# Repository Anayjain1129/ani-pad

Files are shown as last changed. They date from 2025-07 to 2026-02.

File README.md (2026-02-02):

# Ani-Pad
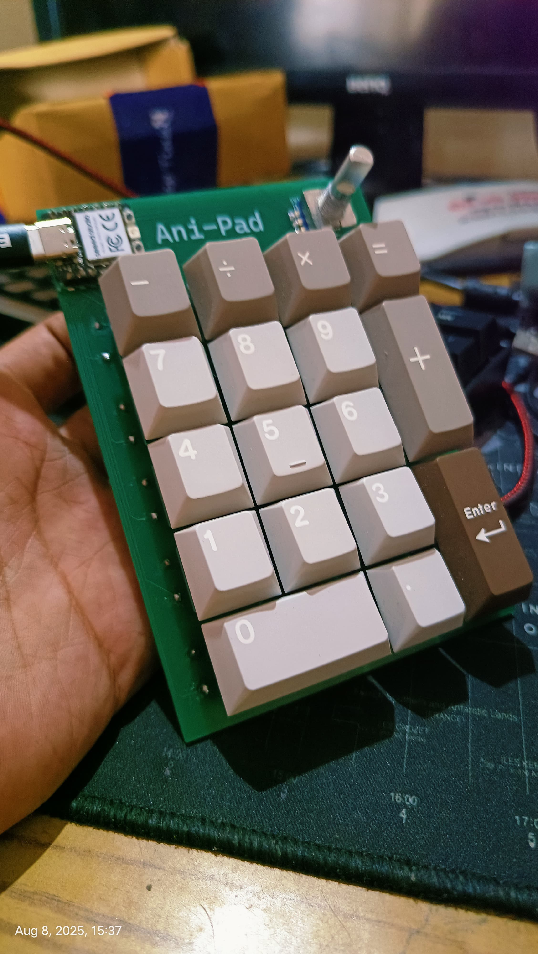
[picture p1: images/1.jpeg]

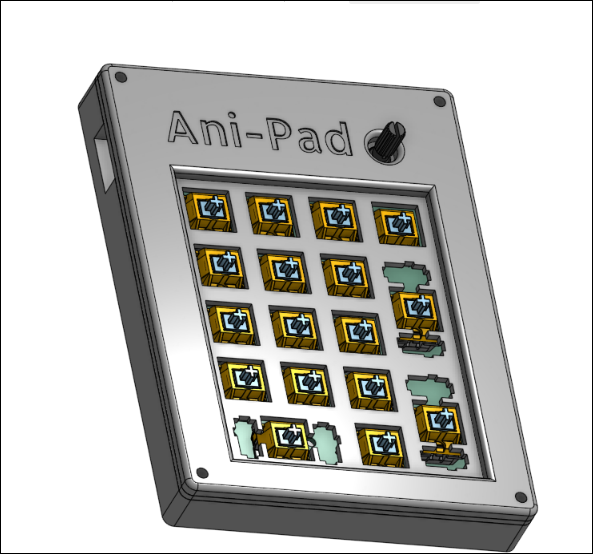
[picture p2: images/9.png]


### Why did I make it?
As I already made hackpad So i wanna make sure that this submission is not hackpad
This is a easier project for highway. So, i made this project cause I use a 60% keeb which does not have a numpad and I really needed that so i asked alex can i make one and got a yes so here we go

### What was the hardest part about this ?
I had tons of issues with making the Firmware, I was really fucked up on Firmware part but I made through.

Features:

- EC11 Rotary Encoder - For Volume, Brightness etc
- 17x keys
- XIAO rp2040
- Traditional Numpad Layout
- QMK firmware
  
### Schematic
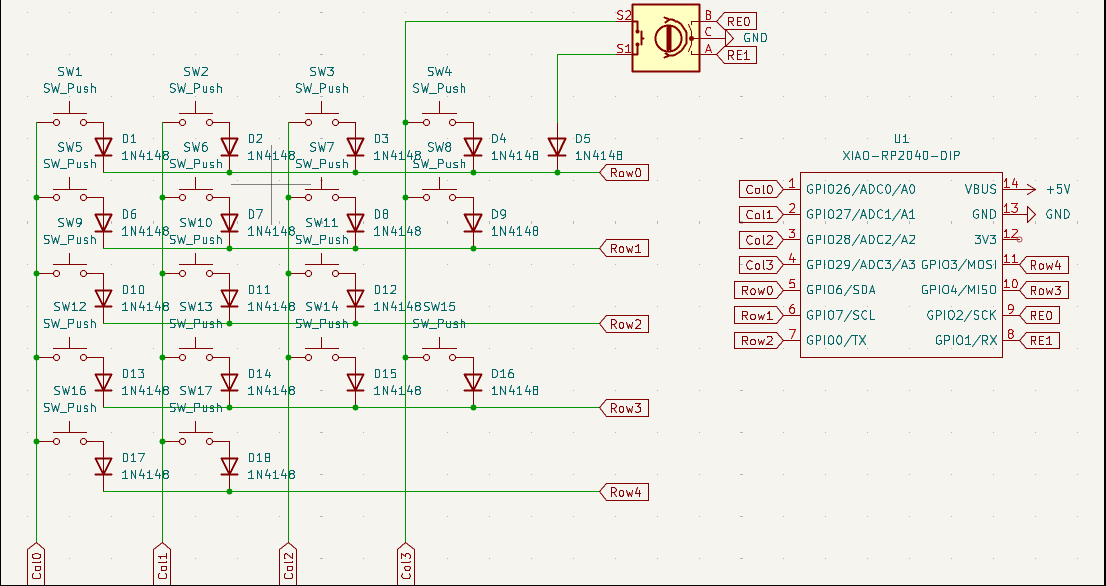
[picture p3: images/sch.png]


### PCB 
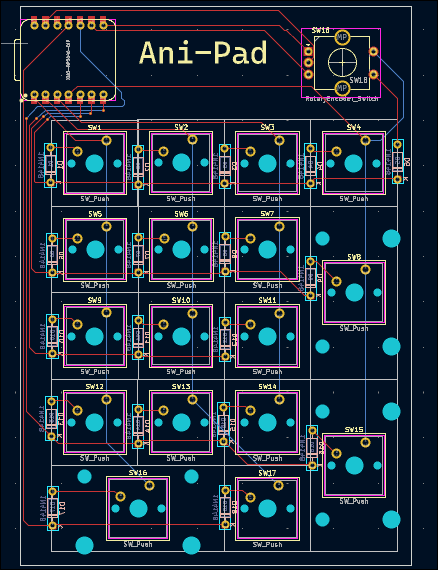
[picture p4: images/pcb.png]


### Case
- Bottom
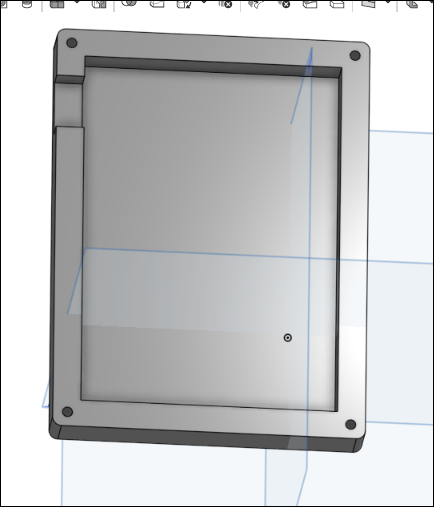
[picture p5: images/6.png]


-Middle plate
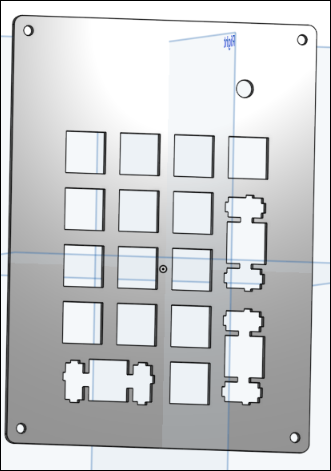
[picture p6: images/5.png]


- Top
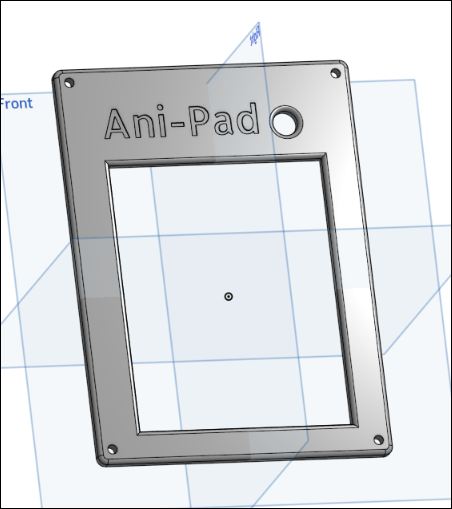
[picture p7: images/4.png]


### 3D view of all parts together 
-PCB
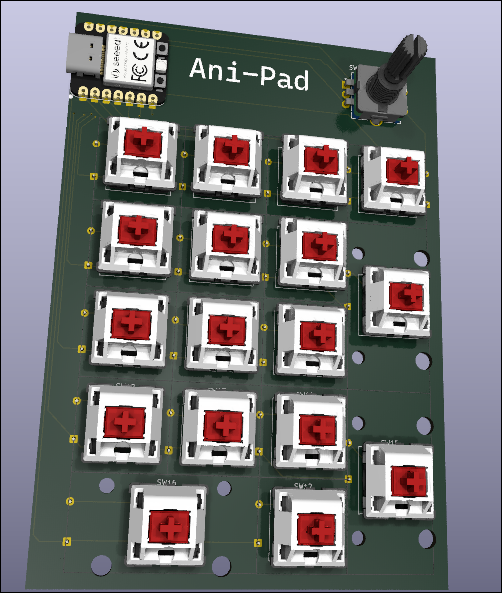
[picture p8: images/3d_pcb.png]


-CAD
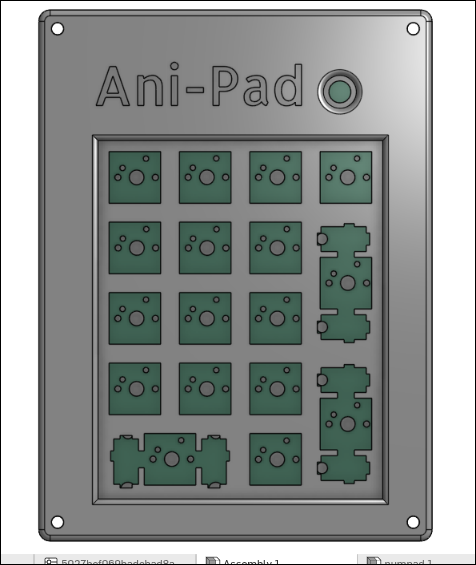
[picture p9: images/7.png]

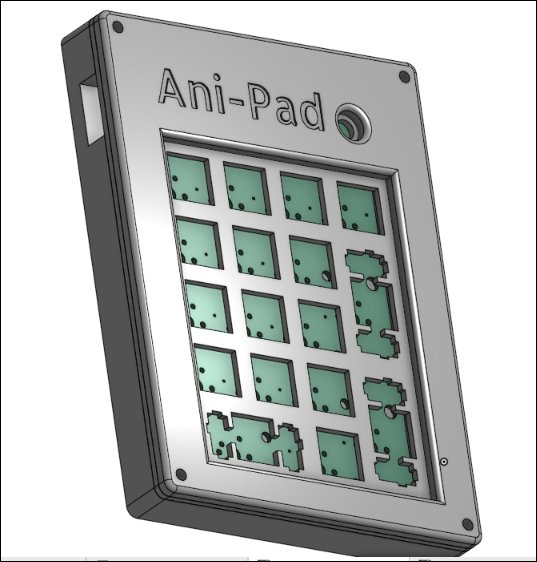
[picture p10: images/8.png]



#Yoututb Link
https://youtube.com/shorts/V-X0GS2zixY?si=X8VkAyLvjKdzDLy9

### BOM
| Name | Qty | Final Price - INR (USD) | Link |
| --- | --- | --- | --- |
| Gateron EF Grayish | 20  | 390 ($4.55) | [here](https://neomacro.in/products/gateron-ef-grayish) |
| Genuine Cherry MX Plate Mount Stabilizers 2U | 3 | 400 {$4.67} | [here](https://stackskb.com/store/genuine-cherry-mx-plate-mount-stabilizers-2u/) |
| KeyKobo Jindo Keycap Set | 1 | 1,700 ($19.84) | [here](https://neomacro.in/products/key-kobo-jindo-keycap-set?_pos=3&_sid=b1e2b9343&_ss=r&variant=48328446116118) |
| Diode 1N4148 Through - Hole | 100 | 169 ($1.97) | [here](https://amzn.in/d/j3eLvoh) |
| EC11 Rotary Encoder | 2 | 178 ($2.08) | [here](https://amzn.in/d/hVRxzij) |
| M3 x 20mm Bolt | 15  | 149 ($1.73) | [here](https://amzn.in/d/8GRQWAB) |
| M3 Nuts | 8 | 100 ($1.16) | [here](https://amzn.in/d/7UQtsm8) |
| M3 x 5mm Heatset Insert | 25  | 179 ($2.09) | [here](https://amzn.in/d/ixybuAc) |
| PCB | 5 | 2,282 ($26.63) | 
| XIAO 2040 | 1 | 1,340 ($15.64) | [here](https://www.amazon.in/Microcontroller-Dual-Core-MicroPython-CircuitPython-Interfaces/dp/B09NNVNW7M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)|
| Top Case | 1 | Print Legion |
| Bottom Case | 1 | Print Legion |
| Middle Plate | 1 | Print Legion |

## Total Pricing 

This Numpad comes out to be 6887 INR ($80.36) When ordering all the parts I'm not including  the 3D parts because I will be getting them from Print Legion.

## Notes :-

I want all the three 3D-printed parts to be printed in black color.
The pricing might slightly vary due to flash sales, and dollar market trends.

## Changes for reboot 
https://drive.google.com/file/d/1S1DNsVMGy2zWwLPmCcZhrC4ZR8giEo4_/view?usp=sharing

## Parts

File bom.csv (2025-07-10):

Name | Qty | Final Price- INR (USD) | Link
Gateron EF Grayish | 20 | 390 ($4.55) | https://neomacro.in/products/gateron-ef-grayish
Genuine Cherry MX Plate Mount Stabilizers 2U | 3 | 400 ($4.67) | https://stackskb.com/store/genuine-cherry-mx-plate-mount-stabilizers-2u/
KeyKobo Jindo Keycap Set | 1 | 1,700 ($19.84) | https://neomacro.in/products/key-kobo-jindo-keycap-set?_pos=3&_sid=b1e2b9343&_ss=r&variant=48328446116118
Diode 1N4148 Through – Hole | 100 | 169 ($1.97) | https://amzn.in/d/j3eLvoh
EC11 Rotary Encoder | 2 | 178 ($2.08) | https://amzn.in/d/hVRxzij
M3 x 20mm Bolt | 15 | 149 ($1.73) | https://amzn.in/d/8GRQWAB
M3 Nuts | 8 | 100 ($1.16) | https://amzn.in/d/7UQtsm8
M3 x 5mm Heatset Insert | 25 | 179 ($2.09) | https://amzn.in/d/ixybuAc
PCB | 5 | 2,282 ($26.63)
XIAO RP2040 | 1 | 1,340 ($15.64) | https://www.amazon.in/Microcontroller-Dual-Core-MicroPython-CircuitPython-Interfaces/dp/B09NNVNW7M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
Top Case | 1 | Print Legion
Bottom Case | 1 | Print Legion
Middle Plate | 1 | Print Legion

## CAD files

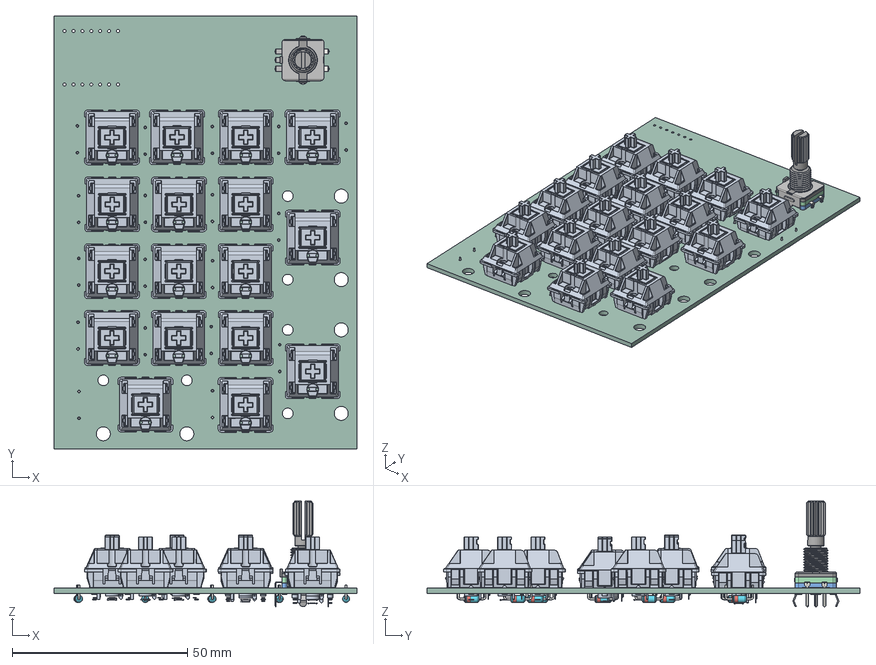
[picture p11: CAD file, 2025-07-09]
PCB/numpad.step
86.3 x 123.4 x 30.1 mm
numpad 1.1.1 x 17
EC11_Rotary_Encoder_Switched
D_DO-35_SOD27_P7.62mm_Horizontal x 18
numpad_PCB

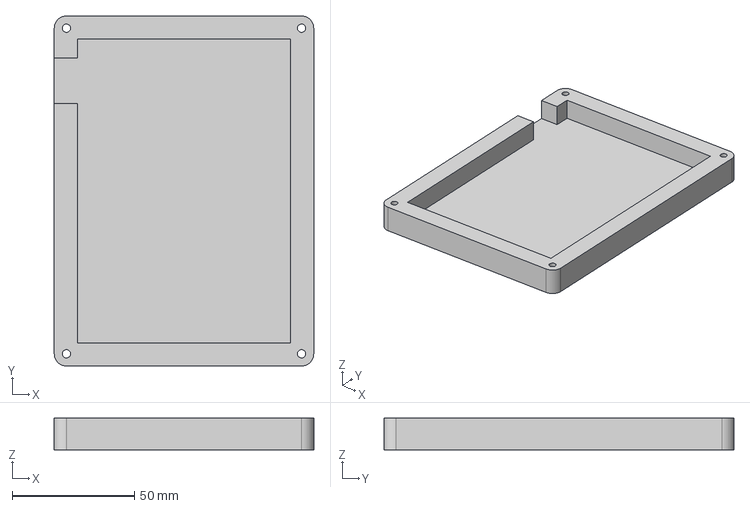
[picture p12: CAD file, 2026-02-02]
Production/CAD/bot.step
106.3 x 143.4 x 13.0 mm

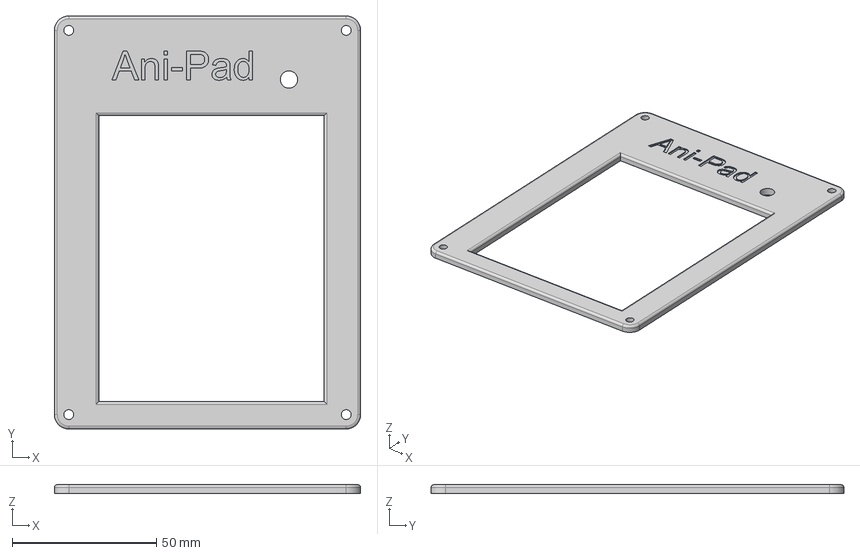
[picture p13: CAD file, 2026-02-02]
Production/CAD/top.step
106.3 x 143.4 x 3.00 mm

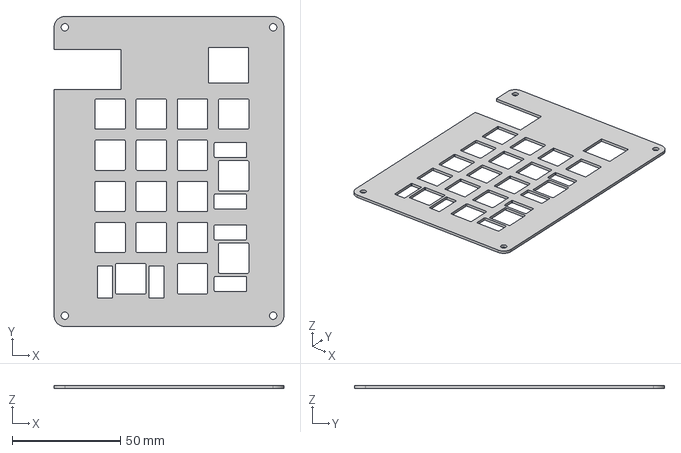
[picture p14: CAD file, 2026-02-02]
Production/CAD/mid.step
106.3 x 143.4 x 1.50 mm

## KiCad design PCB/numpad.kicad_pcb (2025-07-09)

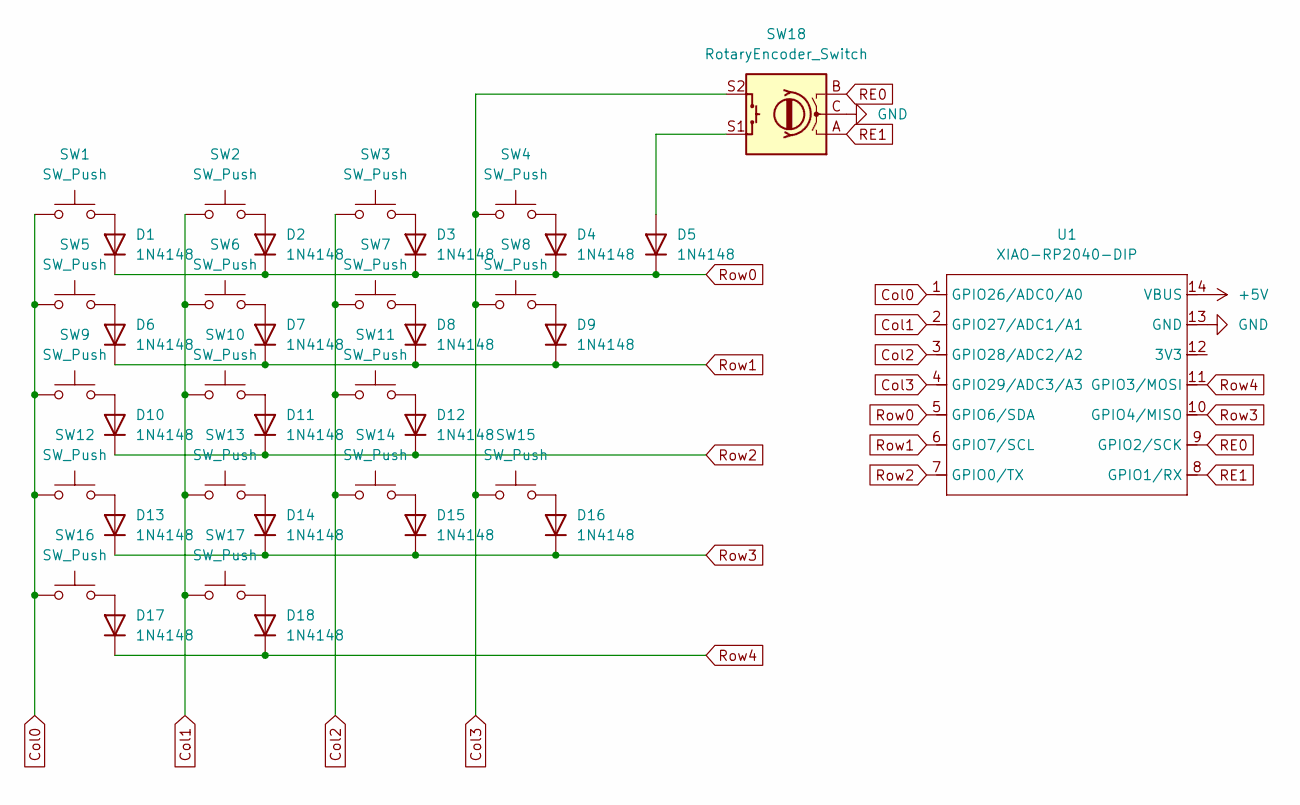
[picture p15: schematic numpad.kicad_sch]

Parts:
D1, D2, D3, D4, D5, D6, D7, D8, D9, D10, D11, D12, D13, D14, D15, D16, D17, D18: 1N4148; D_DO-35_SOD27_P7.62mm_Horizontal
SW1, SW2, SW3, SW4, SW5, SW6, SW7, SW9, SW10, SW11, SW12, SW13, SW14, SW17: SW_Push; SW_Cherry_MX_1.00u_PCB
SW8, SW15: SW_Push; SW_Cherry_MX_2.00u_Vertical_PCB
SW16: SW_Push; SW_Cherry_MX_2.00u_PCB
SW18: RotaryEncoder_Switch; RotaryEncoder_Alps_EC11E-Switch_Vertical_H20mm_CircularMoun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
U1: XIAO-RP2040-DIP

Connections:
+5V: U1.14 (VBUS)
Col0: SW1.1, SW5.1, SW9.1, SW12.1, SW16.1, U1.1 (GPIO26/ADC0/A0)
Col1: SW2.1, SW6.1, SW10.1, SW13.1, SW17.1, U1.2 (GPIO27/ADC1/A1)
Col2: SW3.1, SW7.1, SW11.1, SW14.1, U1.3 (GPIO28/ADC2/A2)
Col3: SW4.1, SW8.1, SW15.1, SW18.S2, U1.4 (GPIO29/ADC3/A3)
GND: SW18.C, U1.13 (GND)
unnamed: D1.2 (A), SW1.2
unnamed: D2.2 (A), SW2.2
unnamed: D3.2 (A), SW3.2
unnamed: D4.2 (A), SW4.2
unnamed: D5.2 (A), SW18.S1
unnamed: D6.2 (A), SW5.2
unnamed: D7.2 (A), SW6.2
unnamed: D8.2 (A), SW7.2
unnamed: D9.2 (A), SW8.2
unnamed: D10.2 (A), SW9.2
unnamed: D11.2 (A), SW10.2
unnamed: D12.2 (A), SW11.2
unnamed: D13.2 (A), SW12.2
unnamed: D14.2 (A), SW13.2
unnamed: D15.2 (A), SW14.2
unnamed: D16.2 (A), SW15.2
unnamed: D17.2 (A), SW16.2
unnamed: D18.2 (A), SW17.2
RE0: SW18.B, U1.9 (GPIO2/SCK)
RE1: SW18.A, U1.8 (GPIO1/RX)
Row0: D1.1 (K), D2.1 (K), D3.1 (K), D4.1 (K), D5.1 (K), U1.5 (GPIO6/SDA)
Row1: D6.1 (K), D7.1 (K), D8.1 (K), D9.1 (K), U1.6 (GPIO7/SCL)
Row2: D10.1 (K), D11.1 (K), D12.1 (K), U1.7 (GPIO0/TX)
Row3: D13.1 (K), D14.1 (K), D15.1 (K), D16.1 (K), U1.10 (GPIO4/MISO)
Row4: D17.1 (K), D18.1 (K), U1.11 (GPIO3/MOSI)

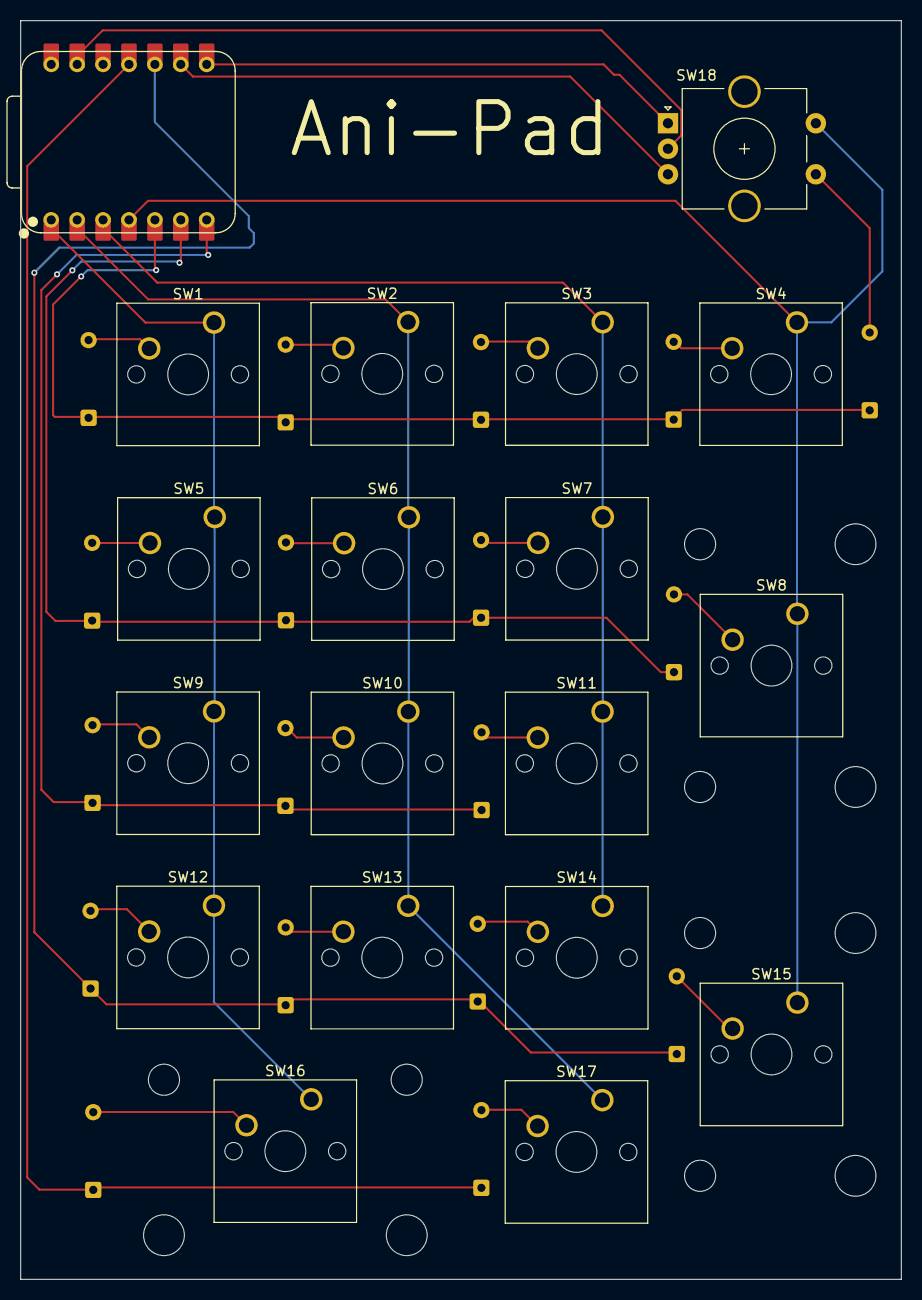
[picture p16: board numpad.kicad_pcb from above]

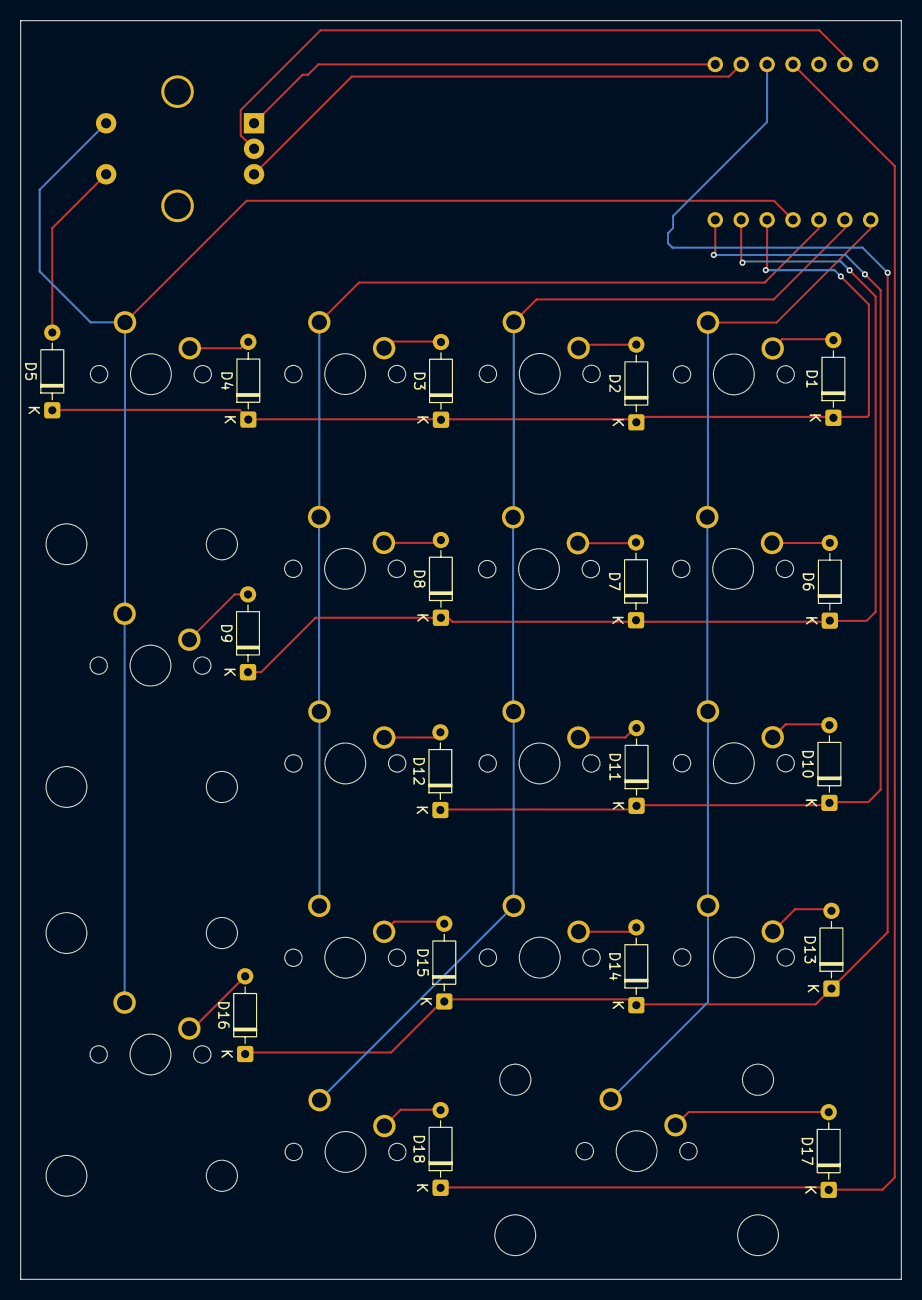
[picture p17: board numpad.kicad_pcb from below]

Board: 2 copper layers, 86.3 x 123.4 mm, 37 parts (18 on the bottom side), 30 nets.

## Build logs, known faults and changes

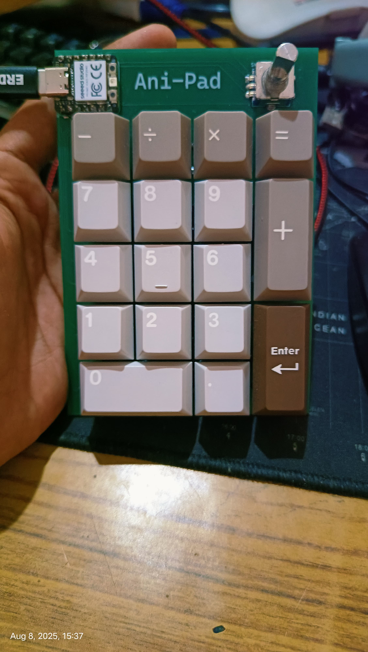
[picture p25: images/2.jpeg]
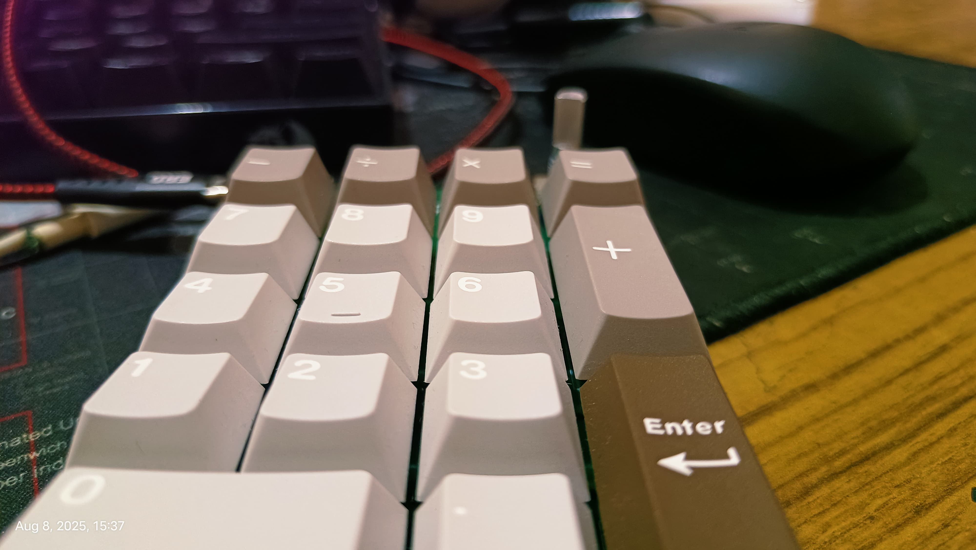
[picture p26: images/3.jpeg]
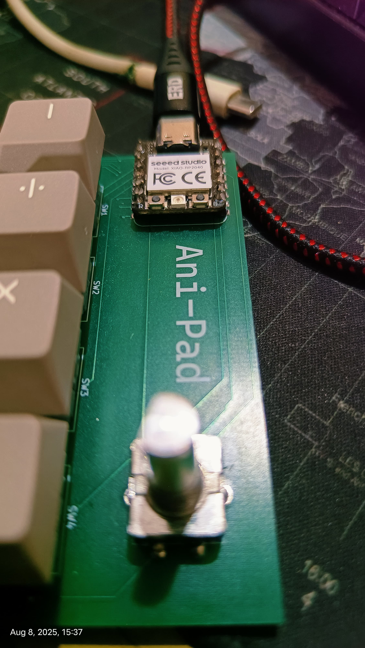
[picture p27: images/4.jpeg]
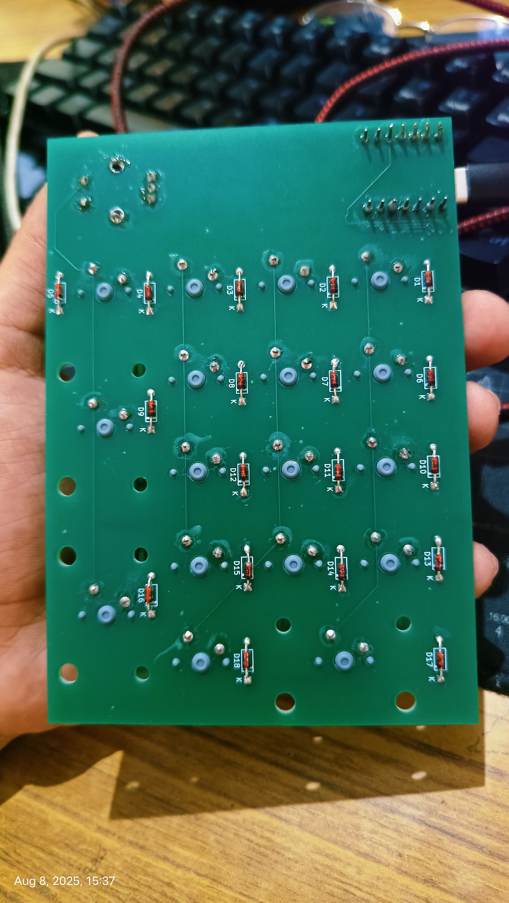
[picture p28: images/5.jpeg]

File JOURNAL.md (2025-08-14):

---
title: "Ani-Pad"
author: "@Anayjain1129"
description: "A numpad"
created_at: "2025-07-08"
---

**Total time spent so far: 10hrs**

## 8th July:
>Alr so, This is not a submission for Hackpad.
>This is a 4 point easier project for highway.
>So, first I did the schematic part It took me around 2hours.Adding a ss for it.



>The layout it pretty simple it's basically a numpad with a RE for increasing or decreasing the volume.

>Then I worked on the PCB.
>the part that i loved so it was really fun time doing it. It took 2 hour.



>Then I added the 3D parts of XIAO the RE and switches. Here's how it looks in 3d.



>After the tutions I did the CAD part I love onshape now, now I know how to properly use it. so here it goes I gave it 2 hours.

>I'm gonna add all the images that i took during the process, so you can understand what i did by lookin at em'.

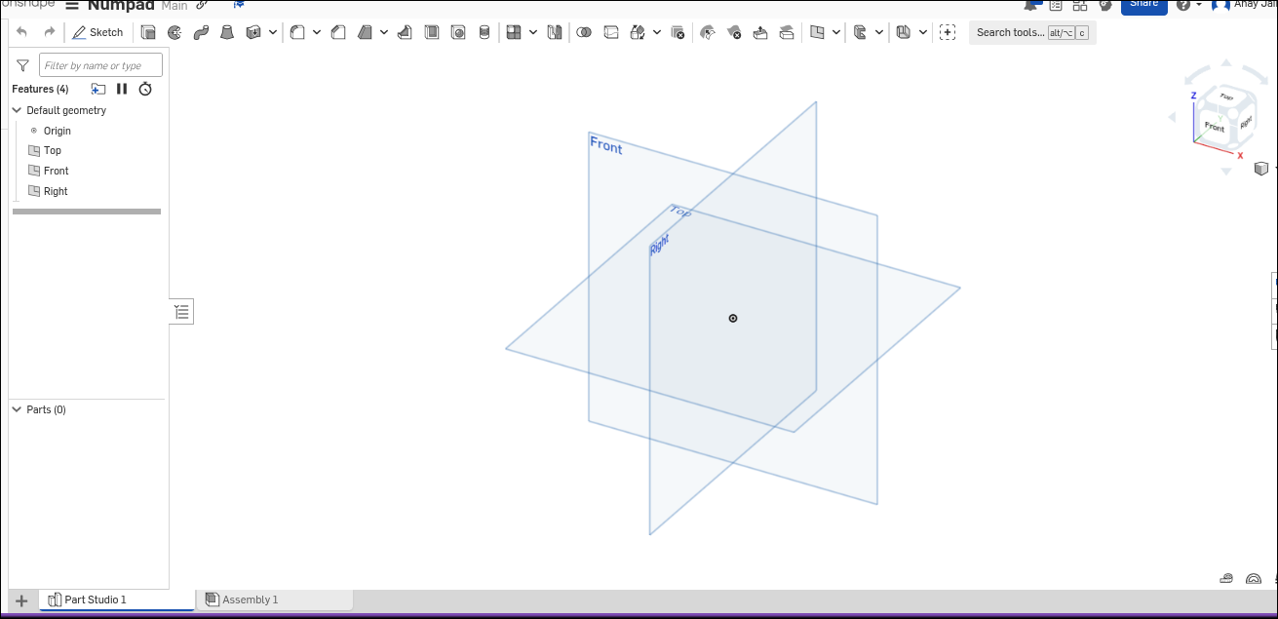
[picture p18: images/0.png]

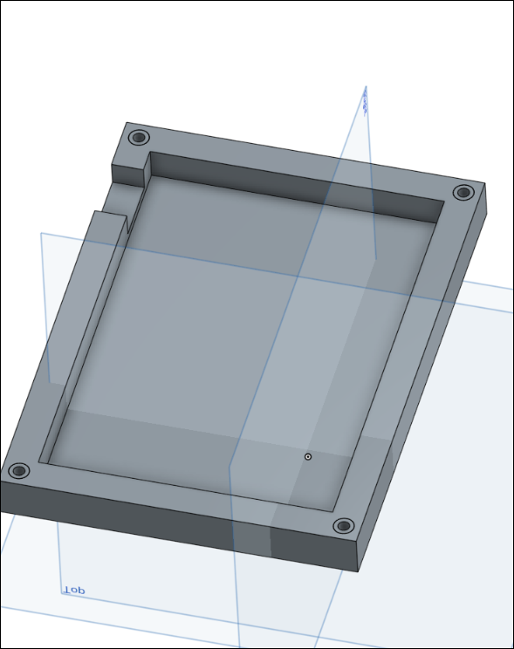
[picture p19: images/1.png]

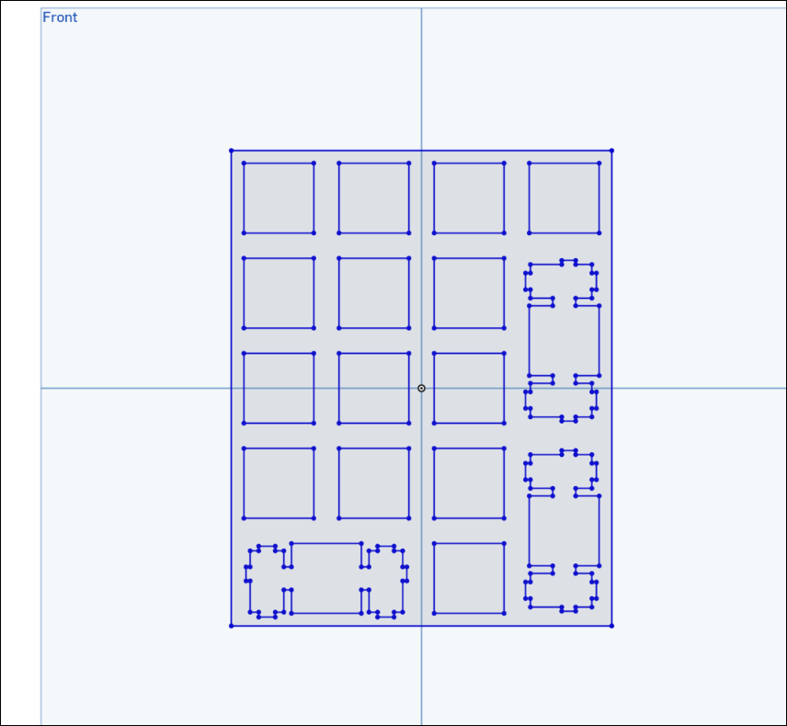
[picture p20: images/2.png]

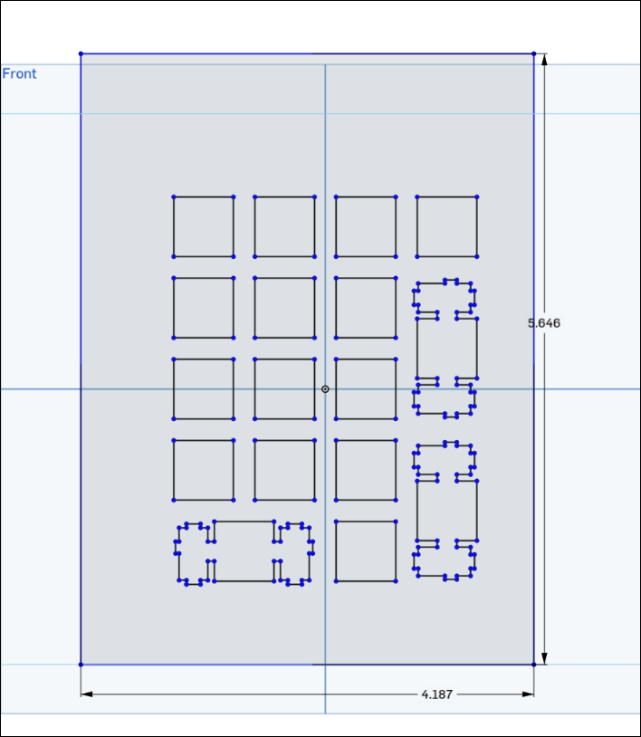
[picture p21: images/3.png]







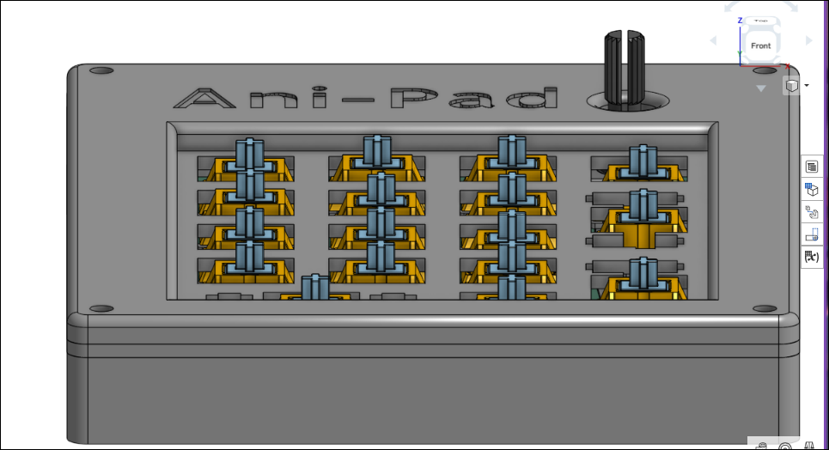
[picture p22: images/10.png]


>Alr, I'm done by everything now I'm gonna start work on firmware tmr maybe.

**Time Spent: 6hrs**

## 9th July: Firmware
>Bruh the Fuck im really fucked up I have the firmware.
>read some documentations actually not some so manyyyyyyyyyyyyyyyy i can link one which helped me so much. https://docs.google.com/document/d/1JV8aVDMf2TwetxhckK0Wdf9FykIQtn7HA-_w5BLeQas/edit?tab=t.0
>Also joe scotto is really awesome He really helped his actually his tutts on yt is are really good.
>took a break. cause of the fucking errors

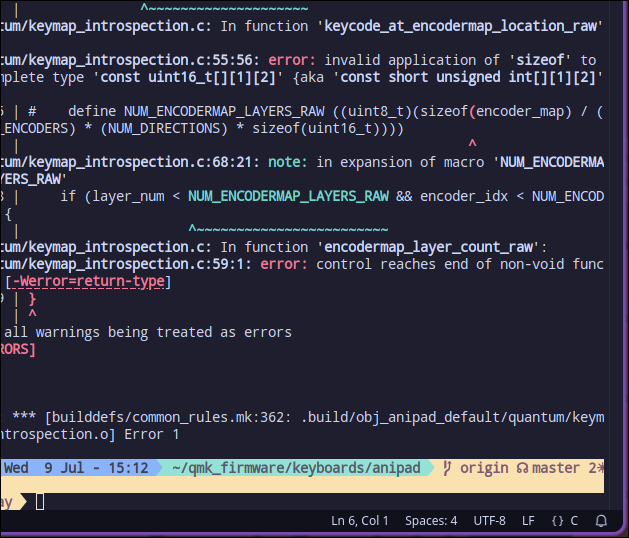
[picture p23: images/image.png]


>Alr I'm back and did twerking and all.
>And here we go I made throught the firmware loophole. :yayy:

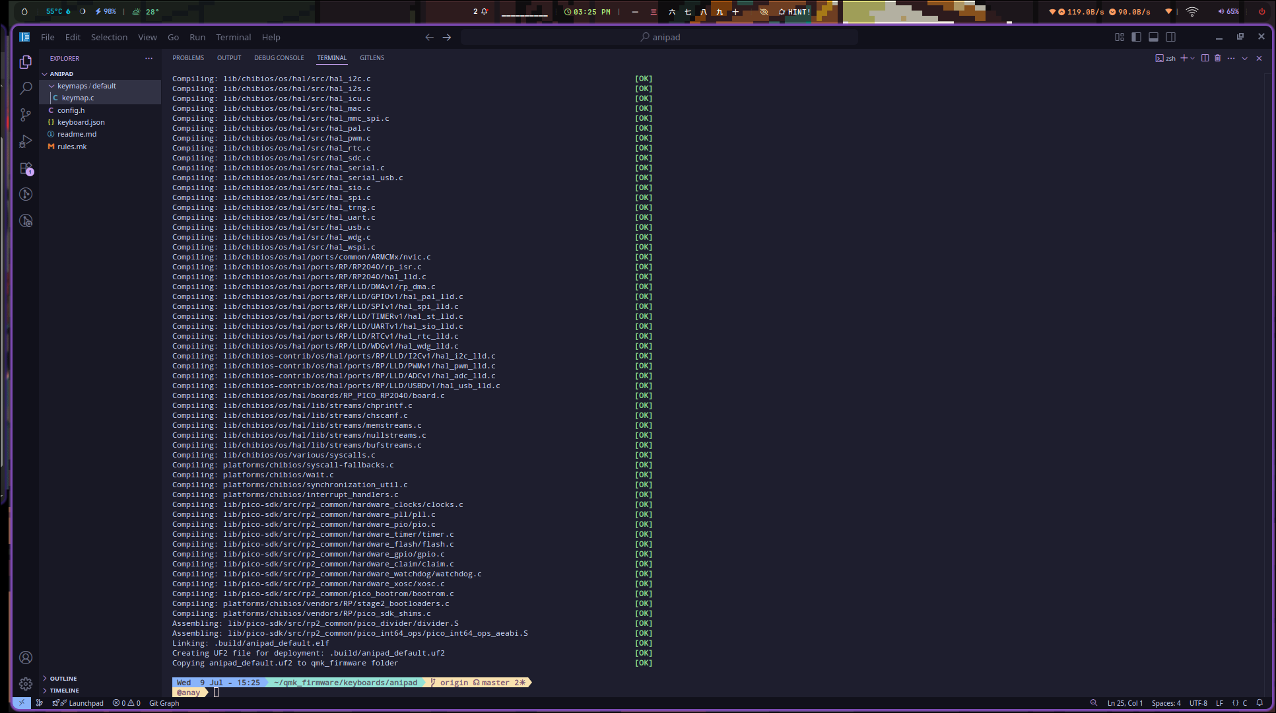
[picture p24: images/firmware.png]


> Then I made the BOM and uploaded the files to github.
>Finding the parts was such a headache.

**Time Spent: 4hrs**

## 31th July:
>So, I had received my PCB and built my project PHYSICALLY
>First I did the diodes and then the MCU and then RE and at the last switches.
>I know basics of soldering so, It wasn't really hard to do that. 
>here are the pictures of the final project.
